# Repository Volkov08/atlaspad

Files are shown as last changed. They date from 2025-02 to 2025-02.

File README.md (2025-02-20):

# Atlaspad

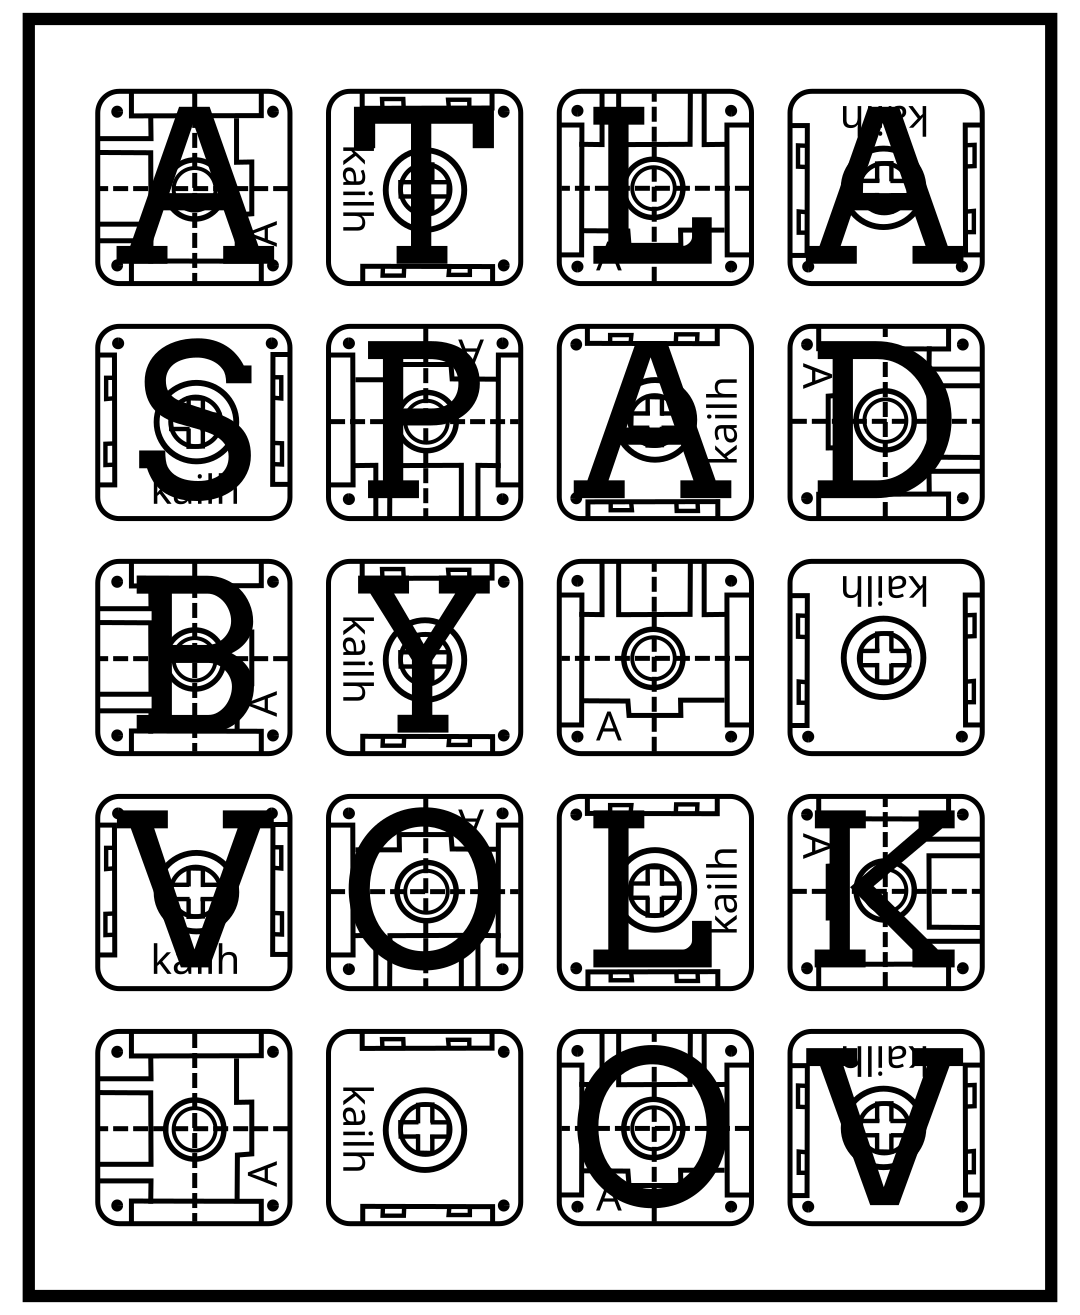
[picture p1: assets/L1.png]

A compact Macropad based on a rp2040 xiao, packed with features!
(Originally intended as a Macropad for playing NMS, that functionality is WIP)

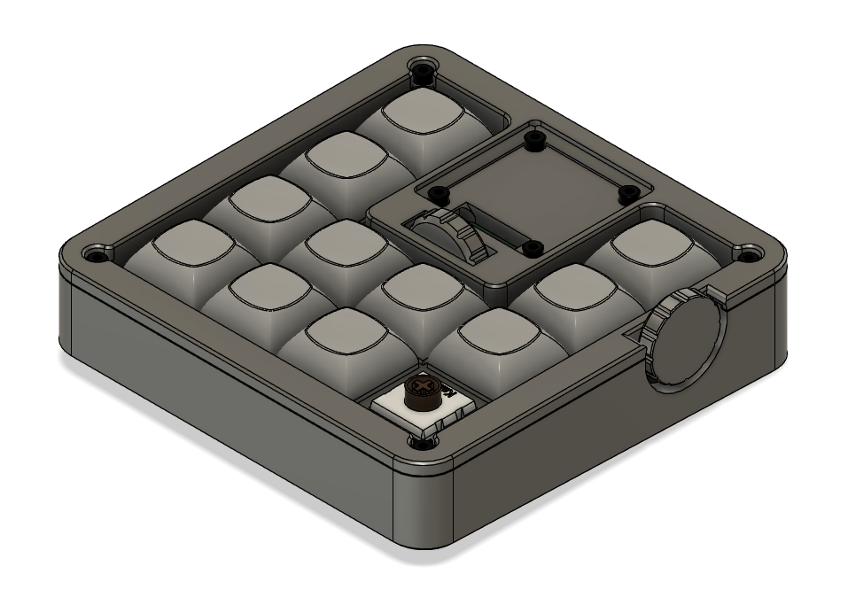
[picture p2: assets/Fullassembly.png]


## Features:

-   12 ChocV2 Low-Profile Switches
-   14 Adressable LEDs Distributed across the Board
-   0.96" OLED Display
-   2 (Horizontal) Encoders

## CAD Model:

The model is based on a sandwich mount (Top,Plate,Base), but also includes the following parts:

-   2 custom wheels for the encoders (slightly slimmer one goes on the side, the thicker one in the middle)
-   an insert into the Top.stl piece thatll allow the OLED to be mounted slightly inset w/o any overhangs when printing

It's held together by 6 M2x16 (Back&OLED) and 2 M2x12 (Front) screws and corresponding hex nuts (DIN 912 & 934)

Exploded Assembly
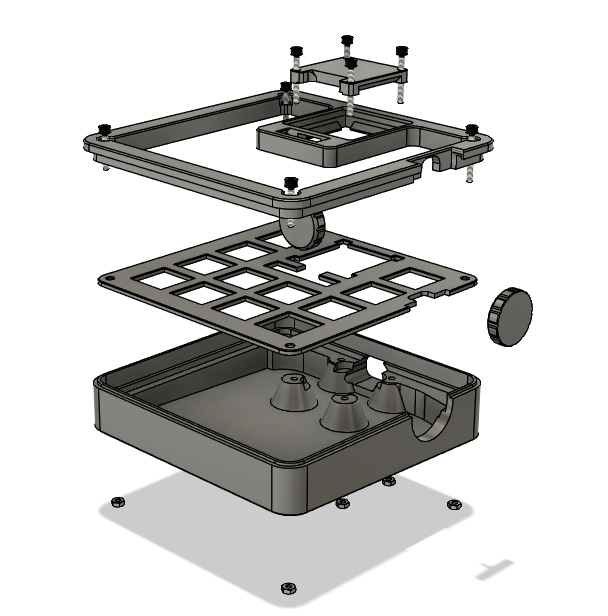
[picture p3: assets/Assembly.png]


(the wheels are press-fit for the encoders / have to be glued, these were the only encoders small enough i could find)
_Designed in Fusion360_

## PCB

(Front side of PCB)
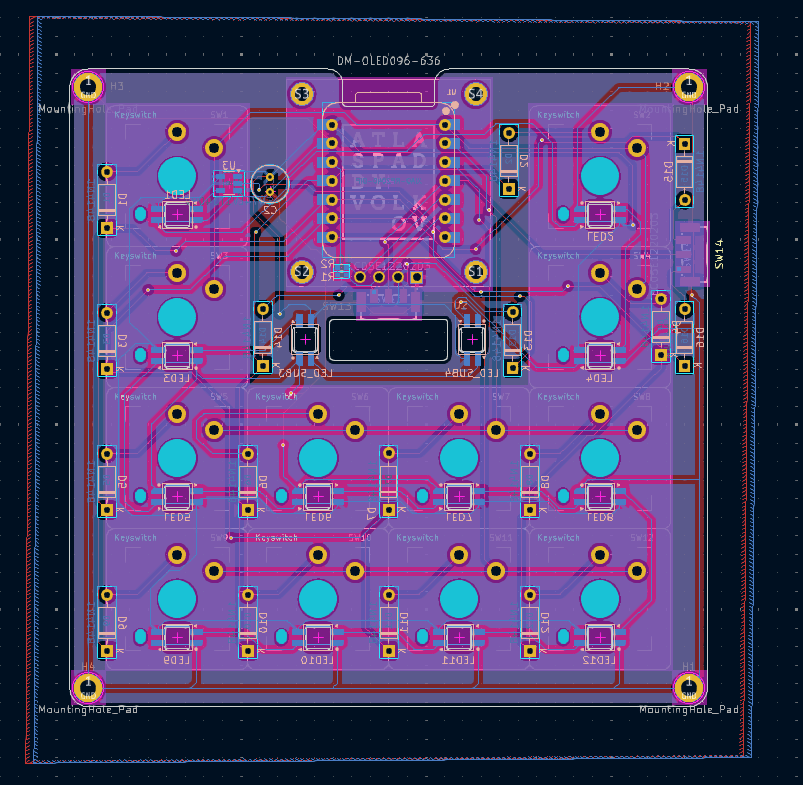
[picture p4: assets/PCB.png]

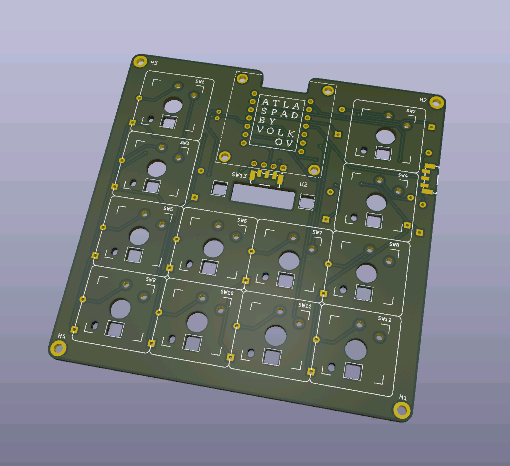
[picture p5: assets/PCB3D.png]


_Designed in KiCad_

## Firmware Overview

This hackpad uses [QMK](https://qmk.fm/) firmware for everything.

Since this is my first time using QMK, only a basic configuration using this layout (mainly for KiCad) is in place:

    /*
     * ┌───┬───────┬───┐
     * │/\ │       │Hom│
     * ├───┤       ├───┤
     * │\/ │       │End│
     * ├───┼───┬───┼───┤
     * │F1 │F2 │F3 │F4 │
     * ├───┼───┼───┼───┤
     * │F5 │F6 │F7 │F8 │
     * └───────┴───┴───┘
     */

The LEDS are in a rainbow pattern :3 and the encoders are configured to sideways scrolling and volume. (encoder configuration might still be a bit buggy)
The OLED currently only displays debug information.

### Features planned

Once i get a working hackpad i can debug on, these are the features i wanna add

-   Multiple layers for different tasks (Fusion Shortcuts, Emojis/Emoticons/ NMS shortcuts)
-   OLED displaying info on layers (maybe even showing the layout itself, as a kind of label for the keys) & Toggle keys
-   LEDs reacting to keypresses, custom wave animation (going out from the pressed key)

## BOM:

Here should be everything you need to make this hackpad besides the PCB and 3d printed parts:

#### Mechanical

-   2x M2x12 Screws
-   6x M2x16 Screws
-   8x M2 Hex nuts

#### Main Features

-   1x Seeed Studio rp2040 xiao
-   12x ChocV2 Switches
-   14x sk6812-mini-e LEDs (sk6812-mini have a different pinout)
-   1x .96" sd1306 OLED Display (if you wanna connect it through a pin header, make sure the Order is GND/VCC/SCL/SDA)
-   2x EC05E1220203 Rotary encoders (SMD)

#### Additional

-   16x 1N4148 THT Diodes

### Optional (but recommended)

-   2x 10k 0402 Resistors
-   1x 22uF Electrolytic cap
-   1x SN74LV1T34DBV level shifter

The hackpad might work w/o these components, but its better to add them.
Here is how to adjust when leaving them out:

-   Resistors are i2c pullups. leave empty
-   Capacitor is a buffer for the LEDs (the can draw >700mA at max Brightness). leave empty
-   Voltage shifter is to accomodate the specified 3.4V minimum data High level, just above the 3.3V outputted by the rp2040. It may work without, but possibly inconsistently. If leaving out, bridge the LED_DIN and LED_DIN_Shifted contacts of the IC Footprint (see below).

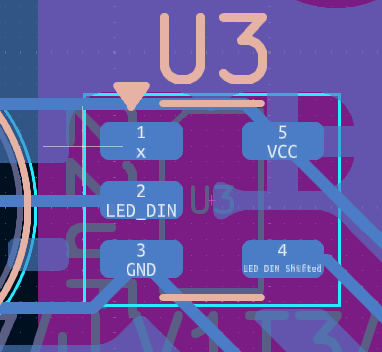
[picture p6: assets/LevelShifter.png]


## Notes:

I hope this works lol .-.

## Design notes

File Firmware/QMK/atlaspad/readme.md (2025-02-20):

# atlaspad

atlaspad

_A short description of the keyboard/project_

-   Keyboard Maintainer: [Volkov08](https://github.com/Volkov08)
-   Custom Macropad built for Hackpad YSWS using the RP2040

Make example for this keyboard (after setting up your build environment):

    make atlaspad:default

Flashing example for this keyboard:

    make atlaspad:default:flash

See the [build environment setup](https://docs.qmk.fm/#/getting_started_build_tools) and the [make instructions](https://docs.qmk.fm/#/getting_started_make_guide) for more information. Brand new to QMK? Start with our [Complete Newbs Guide](https://docs.qmk.fm/#/newbs).

## Bootloader

Enter the bootloader in 3 ways:

-   **Bootmagic reset**: Hold down the key at (0,0) in the matrix (usually the top left key or Escape) and plug in the keyboard
-   **Physical reset button**: Briefly press the button on the back of the PCB - some may have pads you must short instead
-   **Keycode in layout**: Press the key mapped to `QK_BOOT` if it is available

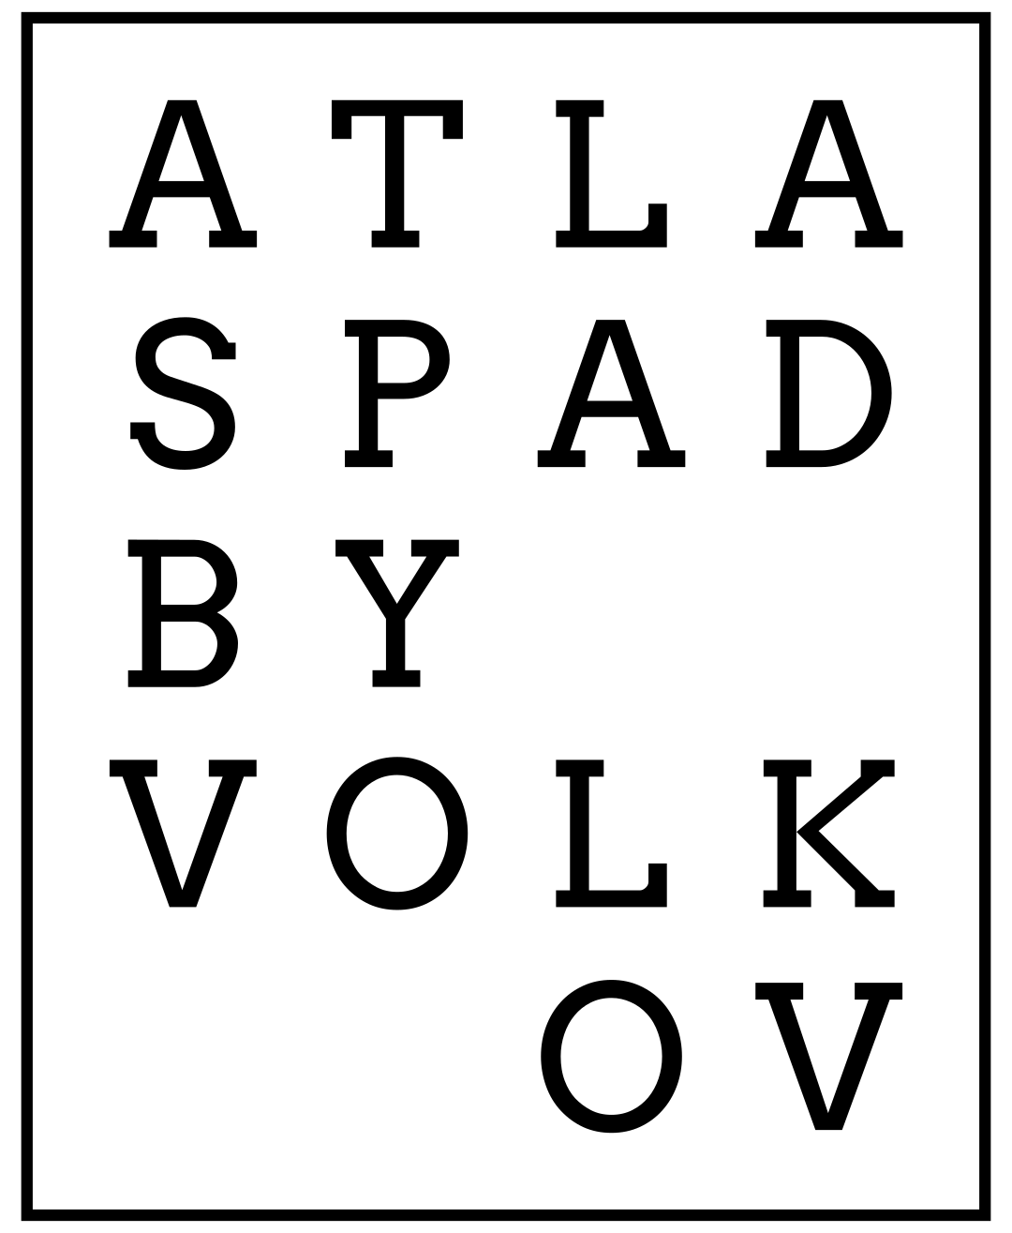
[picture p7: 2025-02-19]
assets/L1Simple.png

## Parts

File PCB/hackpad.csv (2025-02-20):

Id | Designator | Footprint | Quantity | Designation | Supplier and ref
1 | LED_SUB3,LED8,LED2,LED9,LED5,LED_SUB4,LED6,LED7,LED1,LED4,LED11,LED12,LED3,LED10 | SK6812MINI-E-Reverse | 14 | SK6812MINIE
2 | U2 | AZ_OLED-096-SD1306 | 1 | DM-OLED096-636
3 | SW1,SW4,SW6,SW9,SW12,SW8,SW5,SW3,SW11,SW7,SW2,SW10 | Kailh-PG1353-Solderable-1U | 12 | Keyswitch
4 | SW13,SW14 | SW-SMD_EC05E1220203 | 2 | EC05E1220203
5 | D10,D13,D8,D12,D5,D14,D15,D9,D1,D11,D4,D7,D2,D6,D16,D3 | D_DO-35_SOD27_P7.62mm_Horizontal | 16 | 1N4148
6 | R1,R2 | R_0402_1005Metric_Pad0.72x0.64mm_HandSolder | 2 | 10k
7 | U3 | SOT-23-5 | 1 | SN74LV1T34DBV
8 | U1 | XIAO-RP2040-DIP | 1 | XIAO-RP2040-DIP
9 | C2 | C_Radial_D5.0mm_H7.0mm_P2.00mm | 1 | 22uF

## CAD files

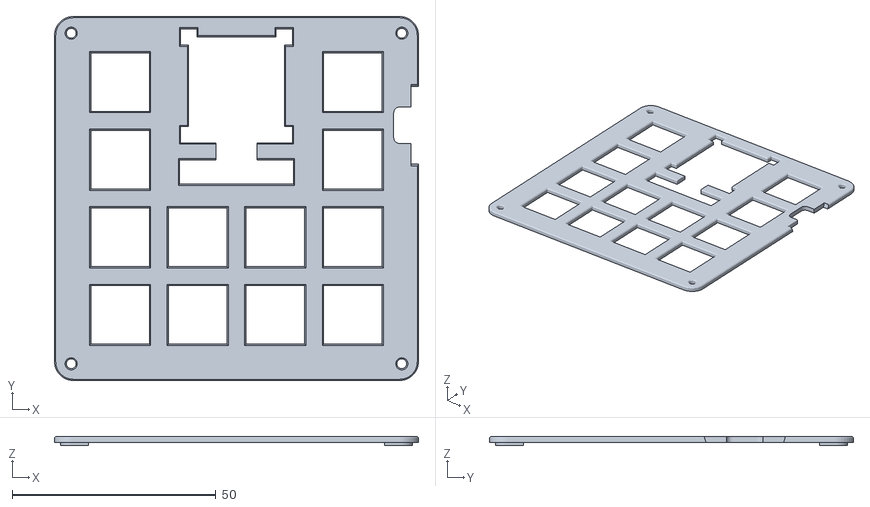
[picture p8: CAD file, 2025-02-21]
production/Plate.stl
89.4 x 89.4 x 2.15

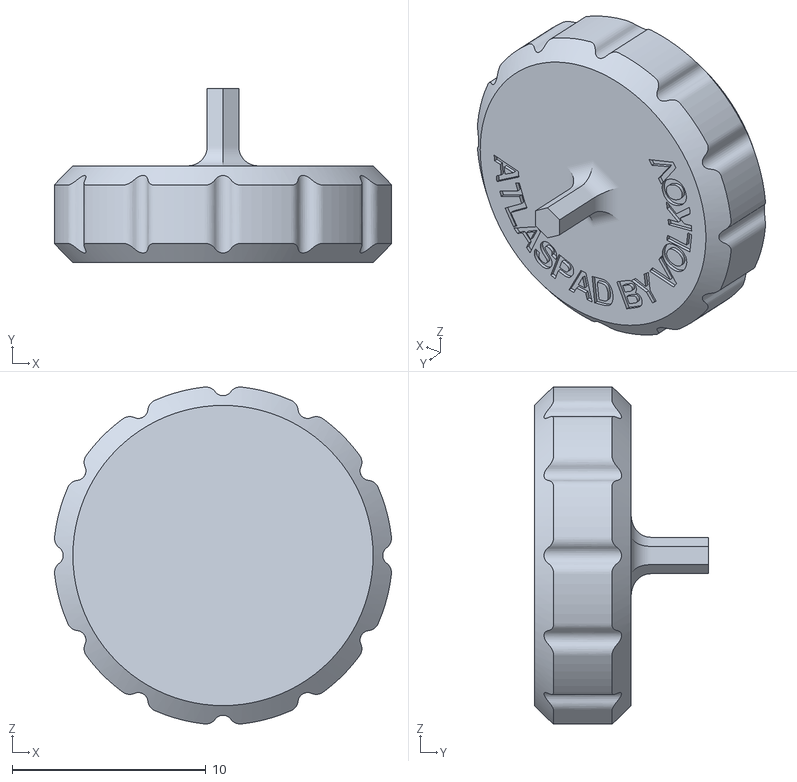
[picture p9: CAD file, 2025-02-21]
production/Wheel1.stl
17.4 x 9.00 x 17.4

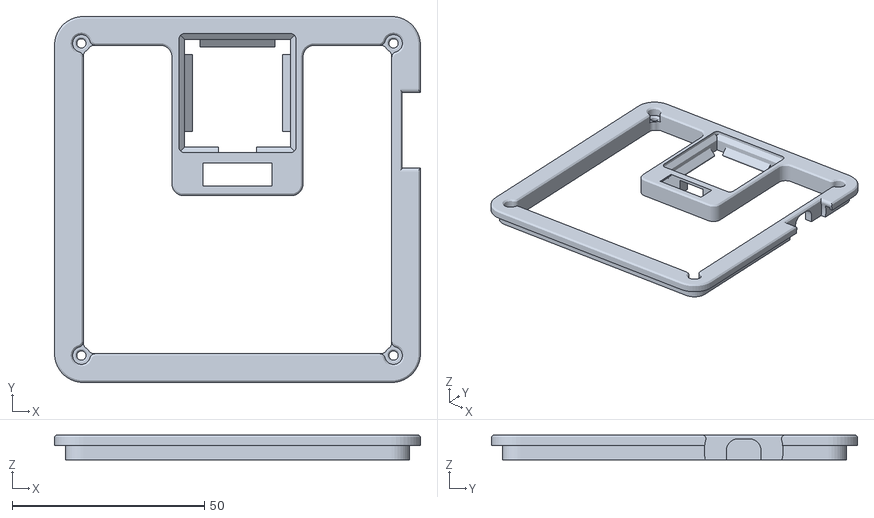
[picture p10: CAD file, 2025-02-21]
production/Top.stl
95.2 x 95.2 x 6.49

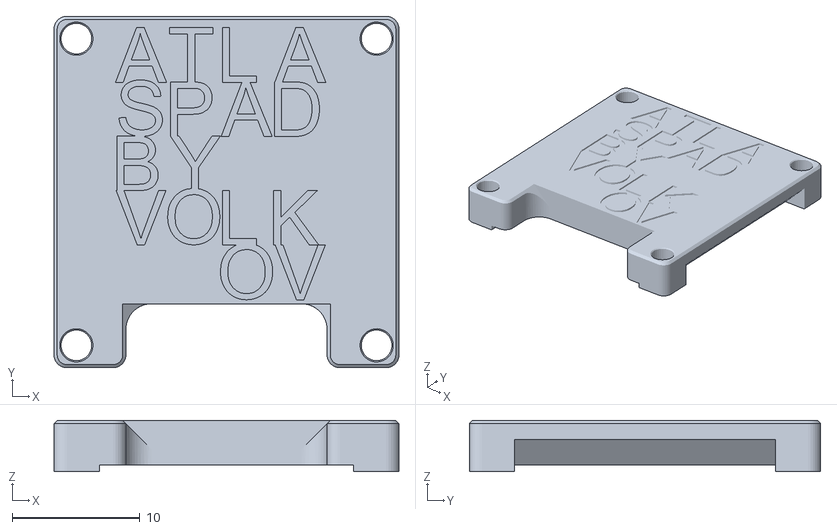
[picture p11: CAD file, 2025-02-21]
production/OLEDInsert.stl
27.0 x 27.5 x 4.00

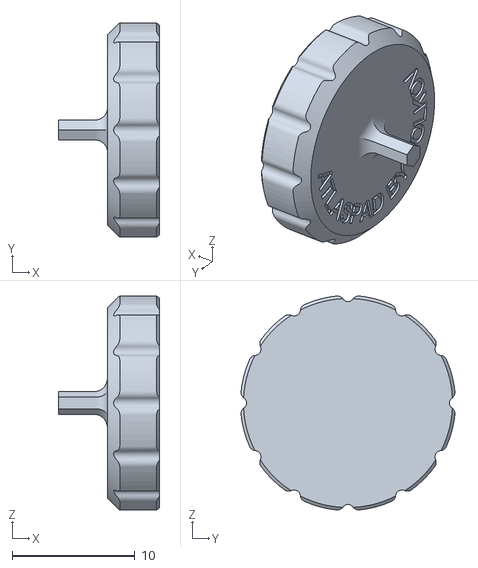
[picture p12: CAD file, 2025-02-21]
production/Wheel2.stl
8.25 x 17.4 x 17.4

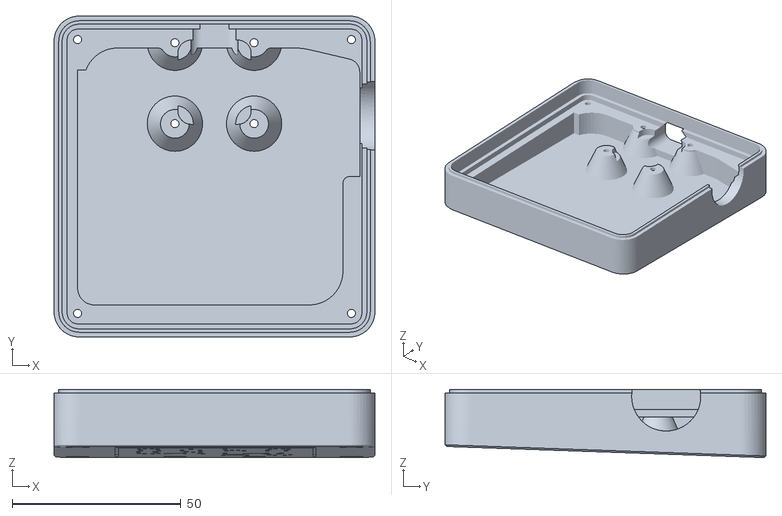
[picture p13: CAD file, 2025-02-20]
production/Base.stl
95.2 x 95.2 x 20.2

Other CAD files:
CAD/HackpadCase v172.step

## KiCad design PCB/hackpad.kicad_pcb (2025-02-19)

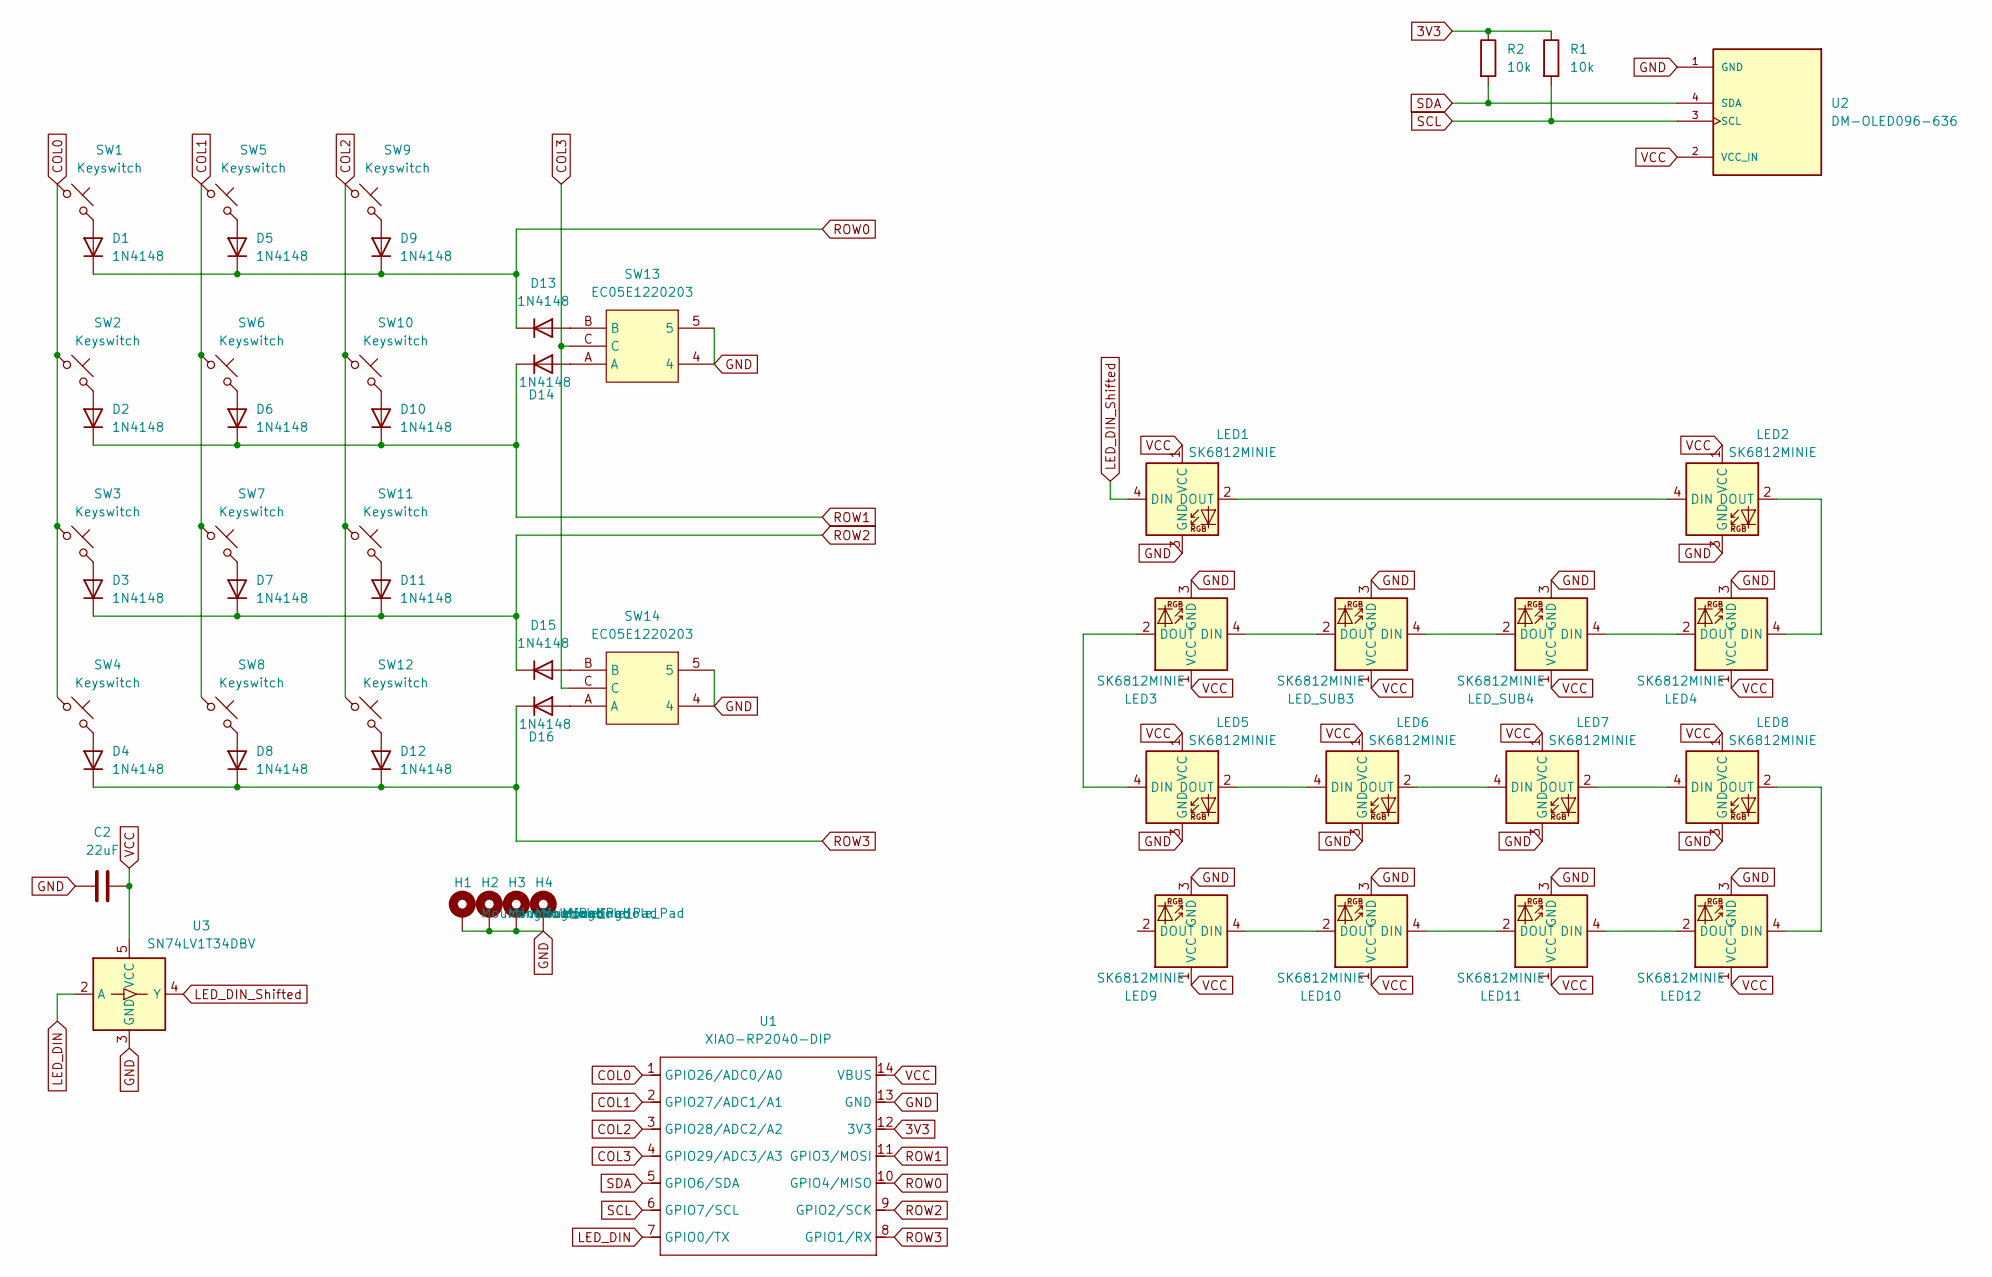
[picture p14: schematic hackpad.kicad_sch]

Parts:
C2: 22uF; C_Radial_D5.0mm_H7.0mm_P2.00mm
D1, D2, D3, D4, D5, D6, D7, D8, D9, D10, D11, D12, D13, D14, D15, D16: 1N4148; D_DO-35_SOD27_P7.62mm_Horizontal
H1, H2, H3, H4: MountingHole_Pad; MountingHole_2.2mm_M2_DIN965_Pad
LED1, LED2, LED3, LED4, LED5, LED6, LED7, LED8, LED9, LED10, LED11, LED12: SK6812MINIE; SK6812MINI-E-Reverse
LED_SUB3, LED_SUB4: SK6812MINIE; SK6812MINI-E-Reverse
R1, R2: 10k; R_0402_1005Metric_Pad0.72x0.64mm_HandSolder
SW1, SW2, SW3, SW4, SW5, SW6, SW7, SW8, SW9, SW10, SW11, SW12: Keyswitch; Kailh-PG1353-Solderable-1U
SW13, SW14: EC05E1220203; SW-SMD_EC05E1220203; LCSC Part C390930
U1: XIAO-RP2040-DIP
U2: DM-OLED096-636; MODULE_DM-OLED096-636; PARTREV 2018-09-10
U3: SN74LV1T34DBV; SOT-23-5

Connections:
3V3: R1.1, R2.1, U1.12 (3V3)
COL0: SW1.1, SW2.1, SW3.1, SW4.1, U1.1 (GPIO26/ADC0/A0)
COL1: SW5.1, SW6.1, SW7.1, SW8.1, U1.2 (GPIO27/ADC1/A1)
COL2: SW9.1, SW10.1, SW11.1, SW12.1, U1.3 (GPIO28/ADC2/A2)
COL3: SW13.C, SW14.C, U1.4 (GPIO29/ADC3/A3)
GND: C2.1, H1.1, H2.1, H3.1, H4.1, LED1.3 (GND), LED2.3 (GND), LED3.3 (GND), LED4.3 (GND), LED5.3 (GND), LED6.3 (GND), LED7.3 (GND), LED8.3 (GND), LED9.3 (GND), LED10.3 (GND), LED11.3 (GND), LED12.3 (GND), LED_SUB3.3 (GND), LED_SUB4.3 (GND), SW13.4, SW13.5, SW14.4, SW14.5, U1.13 (GND), U2.1 (GND), U3.3 (GND)
LED_DIN: U1.7 (GPIO0/TX), U3.2 (A)
LED_DIN_Shifted: LED1.4 (DIN), U3.4 (Y)
unnamed: D1.2 (A), SW1.2
unnamed: D2.2 (A), SW2.2
unnamed: D3.2 (A), SW3.2
unnamed: D4.2 (A), SW4.2
unnamed: D5.2 (A), SW5.2
unnamed: D6.2 (A), SW6.2
unnamed: D7.2 (A), SW7.2
unnamed: D8.2 (A), SW8.2
unnamed: D9.2 (A), SW9.2
unnamed: D10.2 (A), SW10.2
unnamed: D11.2 (A), SW11.2
unnamed: D12.2 (A), SW12.2
unnamed: D13.2 (A), SW13.B
unnamed: D14.2 (A), SW13.A
unnamed: D15.2 (A), SW14.B
unnamed: D16.2 (A), SW14.A
unnamed: LED1.2 (DOUT), LED2.4 (DIN)
unnamed: LED2.2 (DOUT), LED4.4 (DIN)
unnamed: LED3.4 (DIN), LED_SUB3.2 (DOUT)
unnamed: LED3.2 (DOUT), LED5.4 (DIN)
unnamed: LED4.2 (DOUT), LED_SUB4.4 (DIN)
unnamed: LED5.2 (DOUT), LED6.4 (DIN)
unnamed: LED6.2 (DOUT), LED7.4 (DIN)
unnamed: LED7.2 (DOUT), LED8.4 (DIN)
unnamed: LED10.4 (DIN), LED11.2 (DOUT)
unnamed: LED9.4 (DIN), LED10.2 (DOUT)
unnamed: LED11.4 (DIN), LED12.2 (DOUT)
unnamed: LED8.2 (DOUT), LED12.4 (DIN)
unnamed: LED_SUB3.4 (DIN), LED_SUB4.2 (DOUT)
ROW0: D1.1 (K), D5.1 (K), D9.1 (K), D13.1 (K), U1.10 (GPIO4/MISO)
ROW1: D2.1 (K), D6.1 (K), D10.1 (K), D14.1 (K), U1.11 (GPIO3/MOSI)
ROW2: D3.1 (K), D7.1 (K), D11.1 (K), D15.1 (K), U1.9 (GPIO2/SCK)
ROW3: D4.1 (K), D8.1 (K), D12.1 (K), D16.1 (K), U1.8 (GPIO1/RX)
SCL: R1.2, U1.6 (GPIO7/SCL), U2.3 (SCL)
SDA: R2.2, U1.5 (GPIO6/SDA), U2.4 (SDA)
VCC: C2.2, LED1.1 (VCC), LED2.1 (VCC), LED3.1 (VCC), LED4.1 (VCC), LED5.1 (VCC), LED6.1 (VCC), LED7.1 (VCC), LED8.1 (VCC), LED9.1 (VCC), LED10.1 (VCC), LED11.1 (VCC), LED12.1 (VCC), LED_SUB3.1 (VCC), LED_SUB4.1 (VCC), U1.14 (VBUS), U2.2 (VCC_IN), U3.5 (VCC)

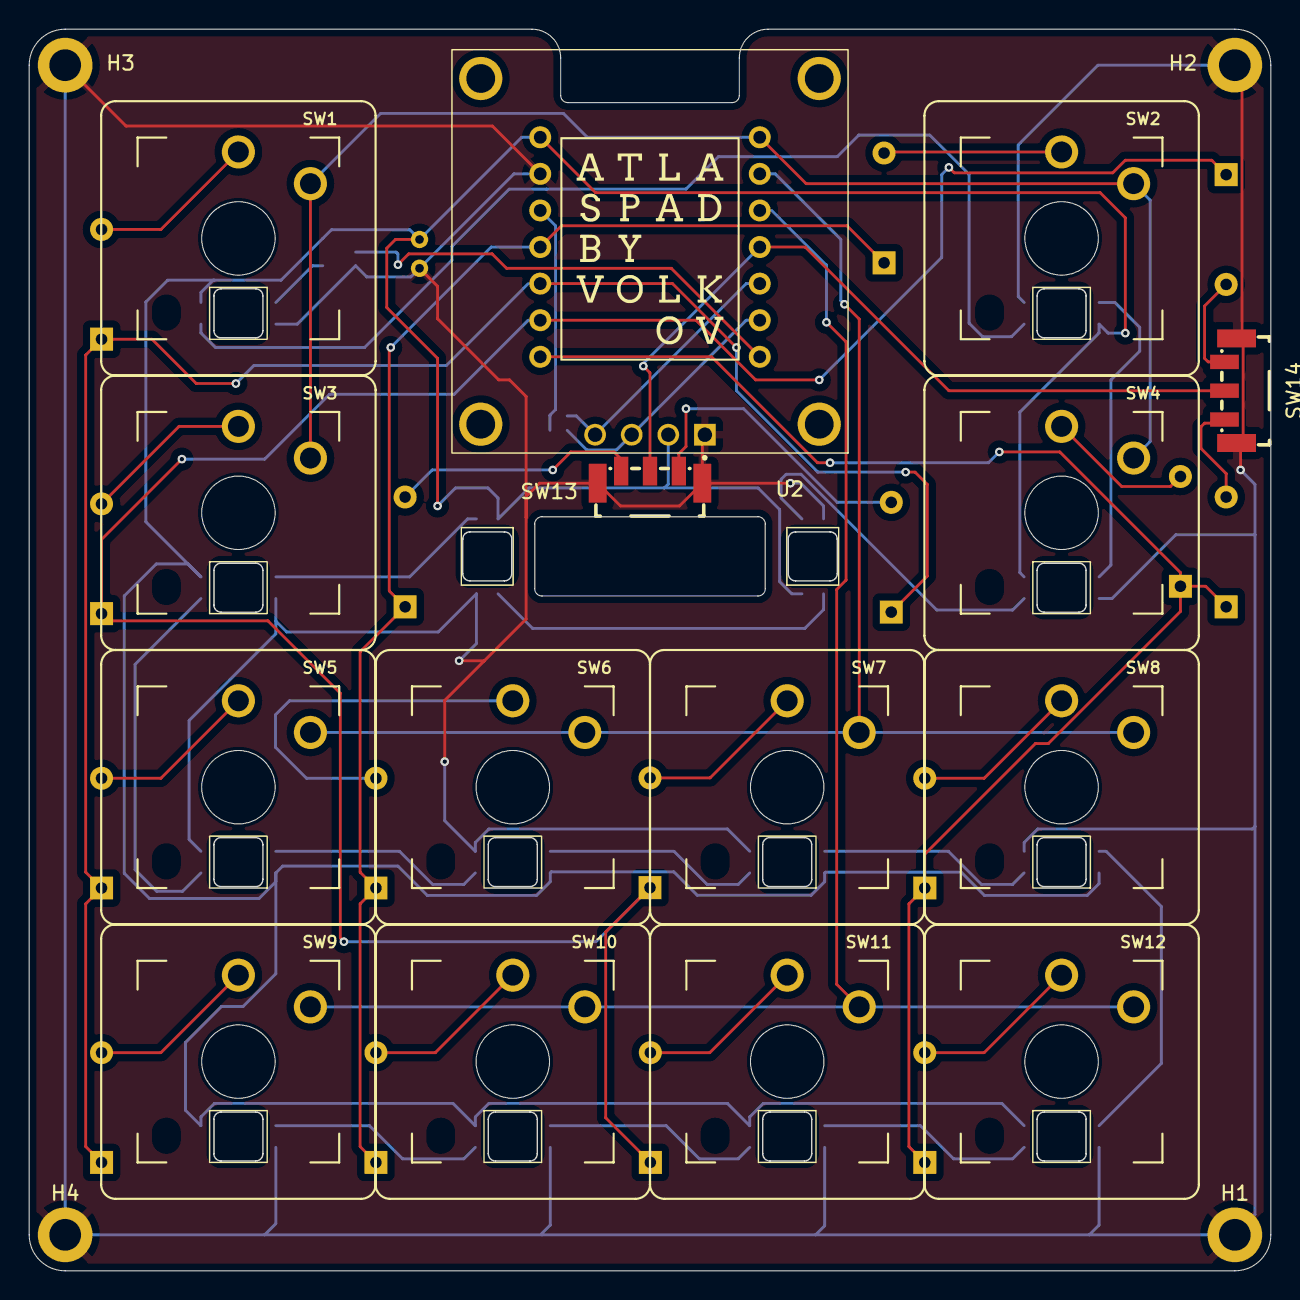
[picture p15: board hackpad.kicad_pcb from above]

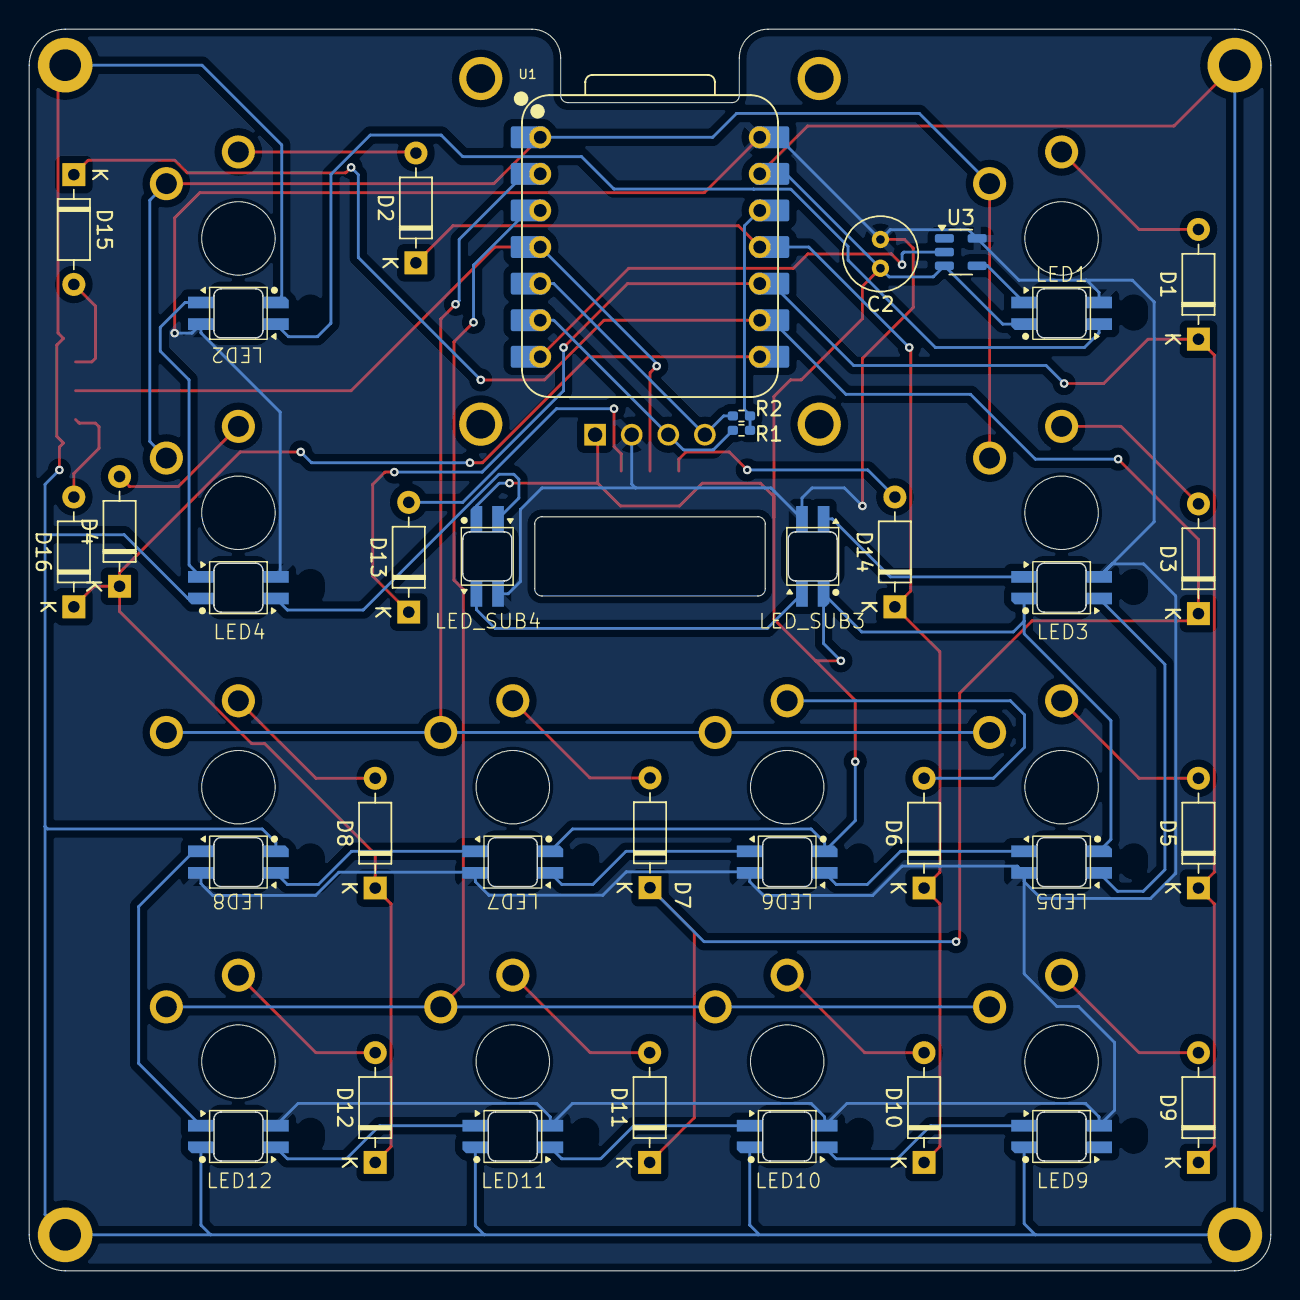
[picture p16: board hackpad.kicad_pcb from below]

Board: 2 copper layers, 86.2 x 86.2 mm, 54 parts (21 on the bottom side), 44 nets.

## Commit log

2025-02-15 did pcb
    [hackpad.kicad_pcb, hackpad.kicad_sch]
2025-02-15 made 3d models of pcb
2025-02-19 case done
    [Base.stl, HackpadCase v153.f3z, OLEDInsert.stl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]
2025-02-20 finished for submission
    [Base.stl, HackpadCase v153.f3z, OLEDInsert.stl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]
2025-02-21 branding uhhh
    [HackpadCase v172.step, OLEDInsert.stl, Plate.stl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]
